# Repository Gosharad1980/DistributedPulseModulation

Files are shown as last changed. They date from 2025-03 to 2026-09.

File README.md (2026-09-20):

# DistributedPulseModulation

Distributed pulse modulation done like with the old P82C150, but with descrete components

## Theory of operation

With a regular Pulse Width Modulation (PWM), all the pulses are grouped in a same and unique pulse over the whole period.
On Distributed Pulse Modulation (DPM) and Dyadic Descrete Pulse Modulation (DDPM), the aim is to distribute all the "sub-pulses" throughout the whole period.

## Two advantages :
* spectrum with more high frequencies than PWM : easier filtering in case of A/D conversion
* as the pulse distribution is continuously evaluated : a threshold modification, before the period end, is taken into account without delay

### Old P82C150 for DPM implementation
[P82C150 - Application note](https://www.nxp.com/docs/en/application-note/AN94088.pdf)

[P82C150 datasheet](https://www.digchip.com/datasheets/parts/datasheet/364/P82C150AHT-pdf.php)

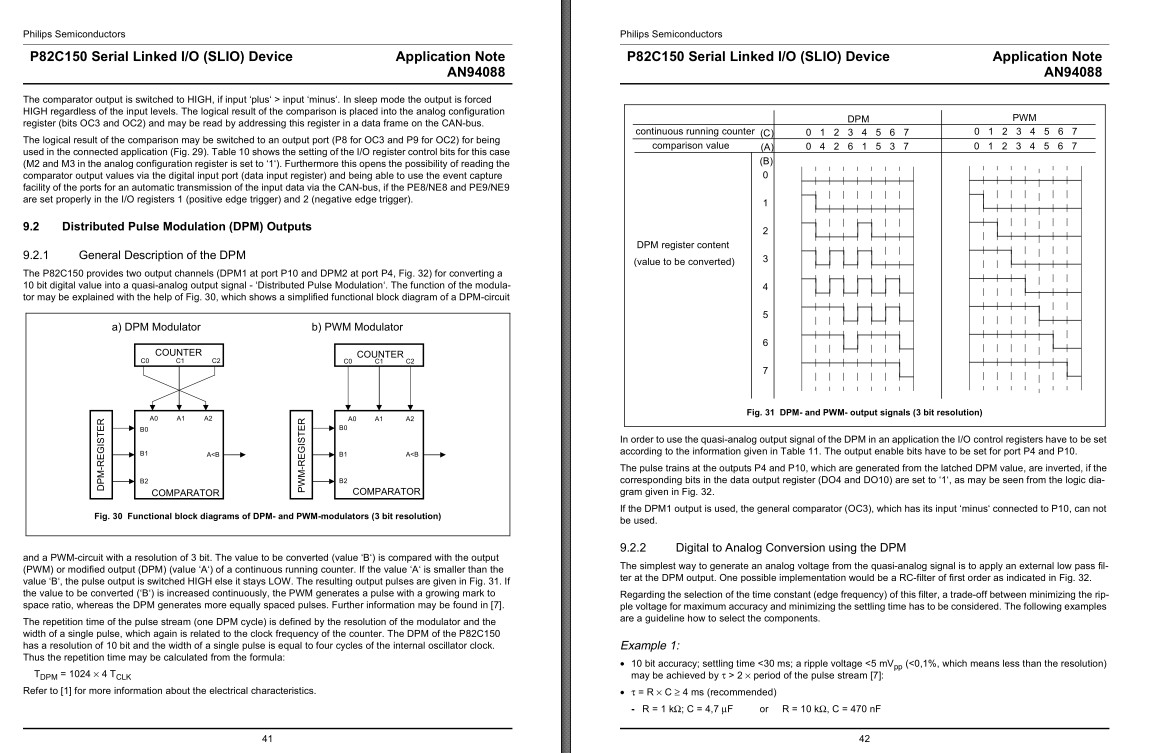
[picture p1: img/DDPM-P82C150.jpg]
DDPM-P82C150


### DDPM implementation based on Paolo S. Crovetti thesis
[Thèse : Paolo S. Crovetti](https://www.researchgate.net/publication/309012492_All-Digital_High_Resolution_DA_Conversion_by_Dyadic_Digital_Pulse_Modulation)

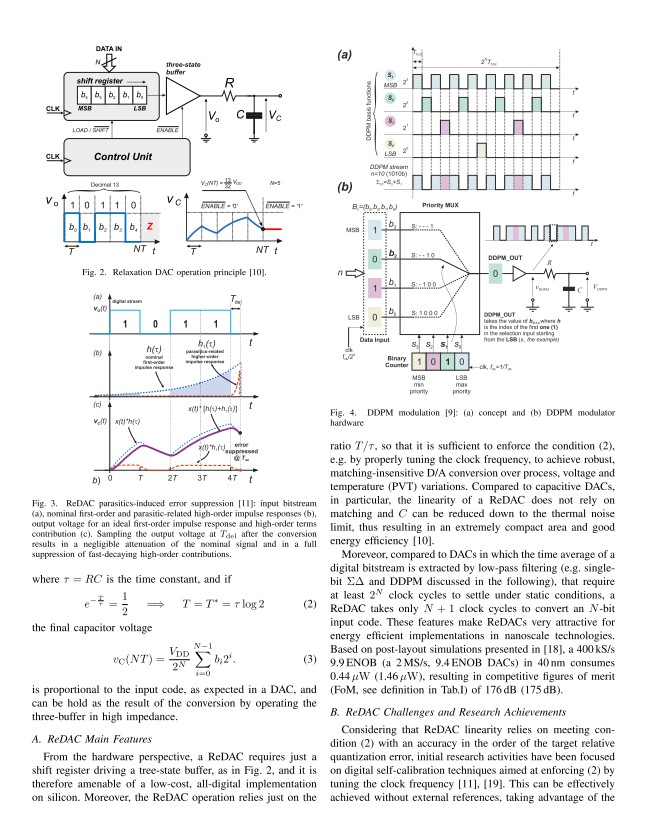
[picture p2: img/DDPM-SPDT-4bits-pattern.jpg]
DDPM-SPDT-4bits-pattern


## The breakout board

###  Features
	PWM (Pulse Width Modulation)
	DPM P82C150-like (Distributed Pulse Modulation)
	DDPM (Dyadic Discrete Pulse Modulation)

### MCP23017 Port A & B

	MCP23017 is an I2C 16bits IO expander
	Port A & B are used to control the board
	Prescaler decoding values :
	0x00	1
	0x01	2
	0x02	8
	0x03	16
	0x04	64
	0x05	256
	0x06	1024
	0x07	4096

Port A & B

### Overview

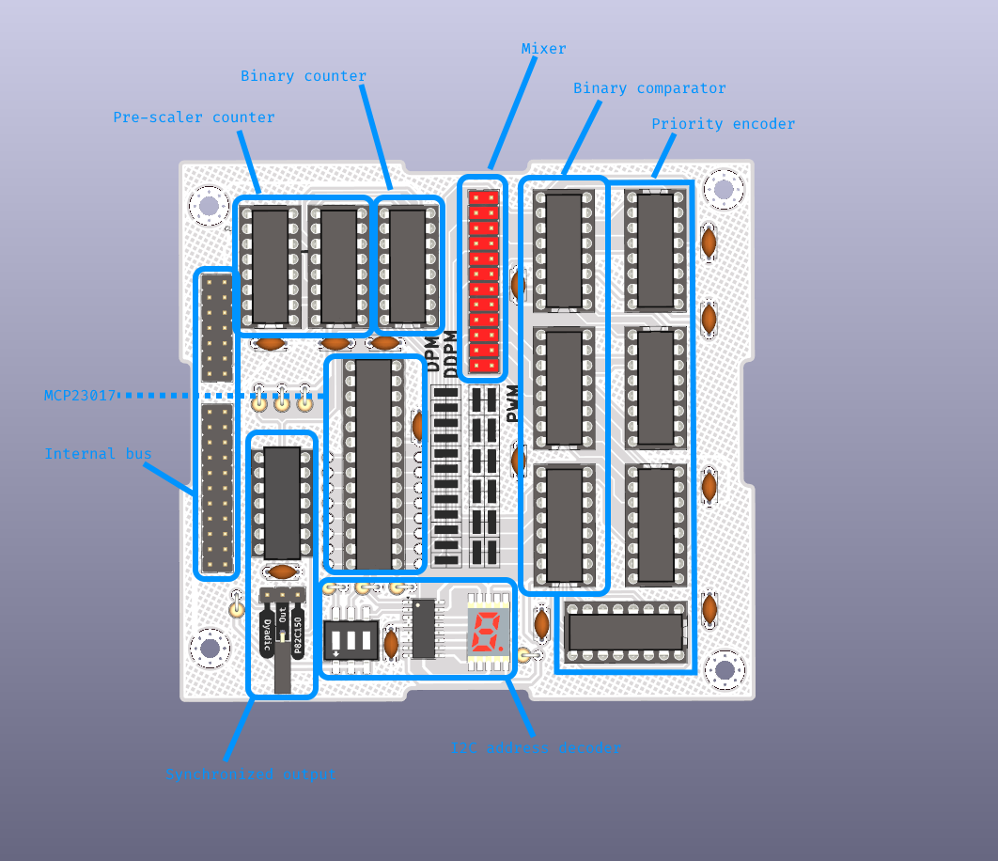
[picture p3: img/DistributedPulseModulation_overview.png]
DistributedPulseModulation_overview


## Choose your feature and do not populate the useless chips

### PWM

* do not populate the CD74HCT4053
* place the jumpers as describe in the silkscreen schematic (PWM)

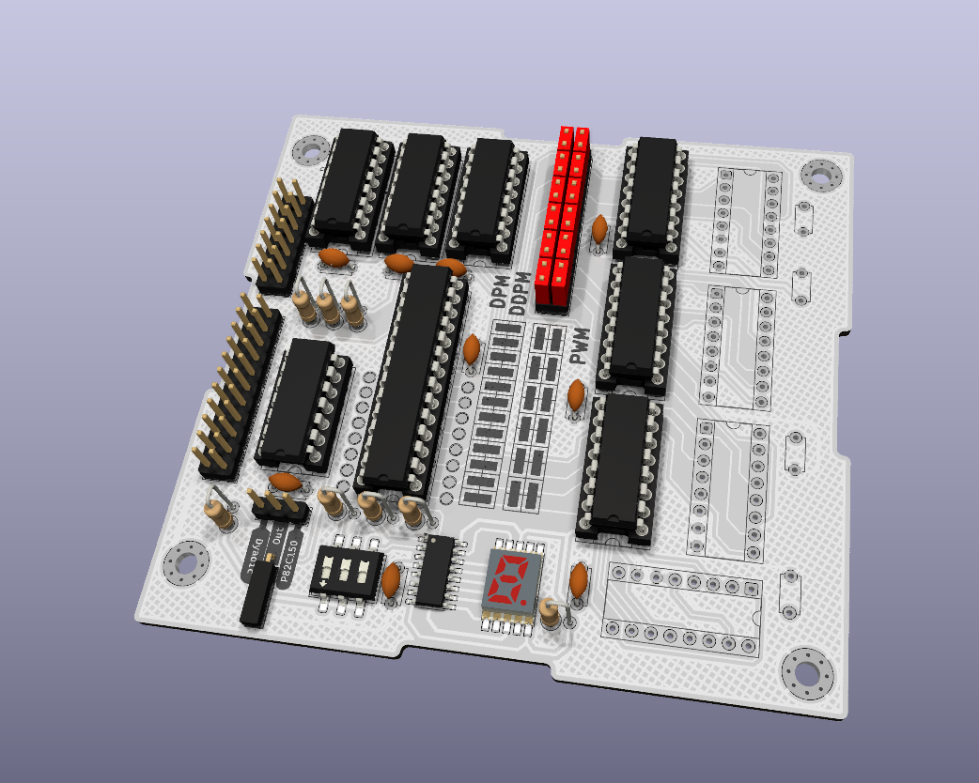
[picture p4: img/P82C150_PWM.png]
P82C150_PWM


### DPM

* do not populate the CD74HCT4053
* place the jumpers as describe in the silkscreen schematic (DPM/DDPM)

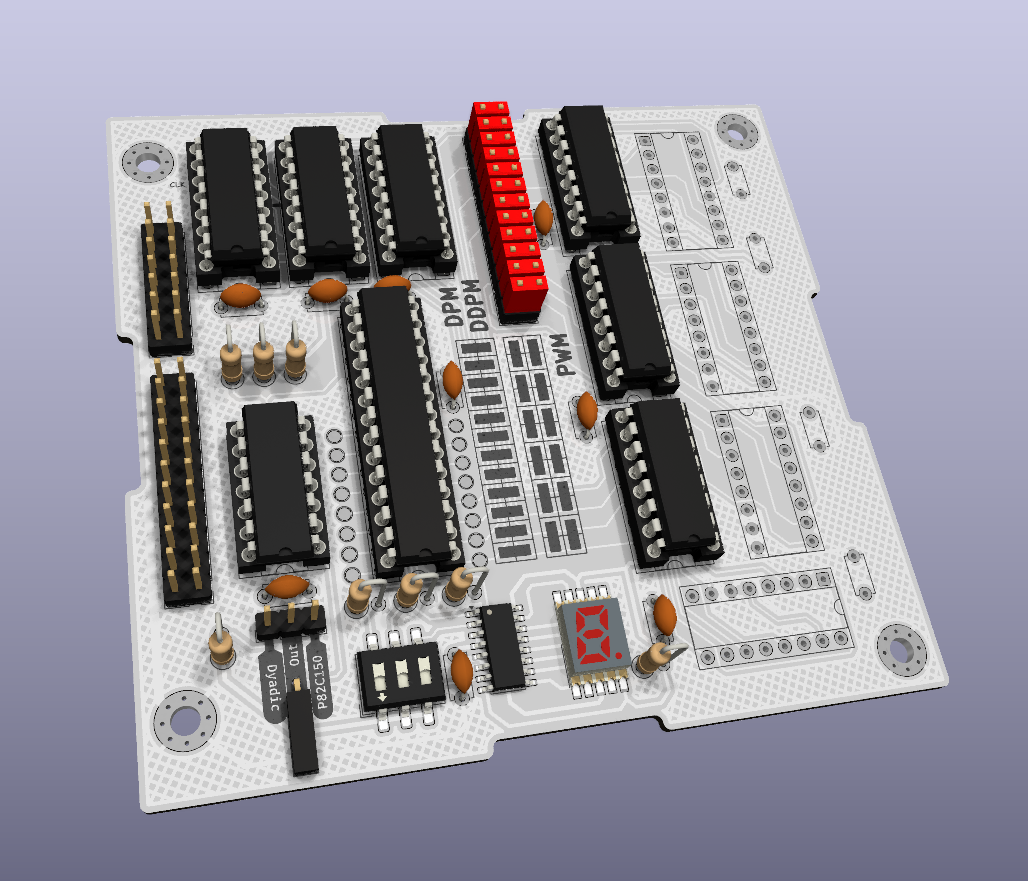
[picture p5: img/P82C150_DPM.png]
P82C150_DPM


### DDPM

* do not populate the 74LS85
* place the jumpers as describe in the silkscreen schematic (DPM/DDPM)

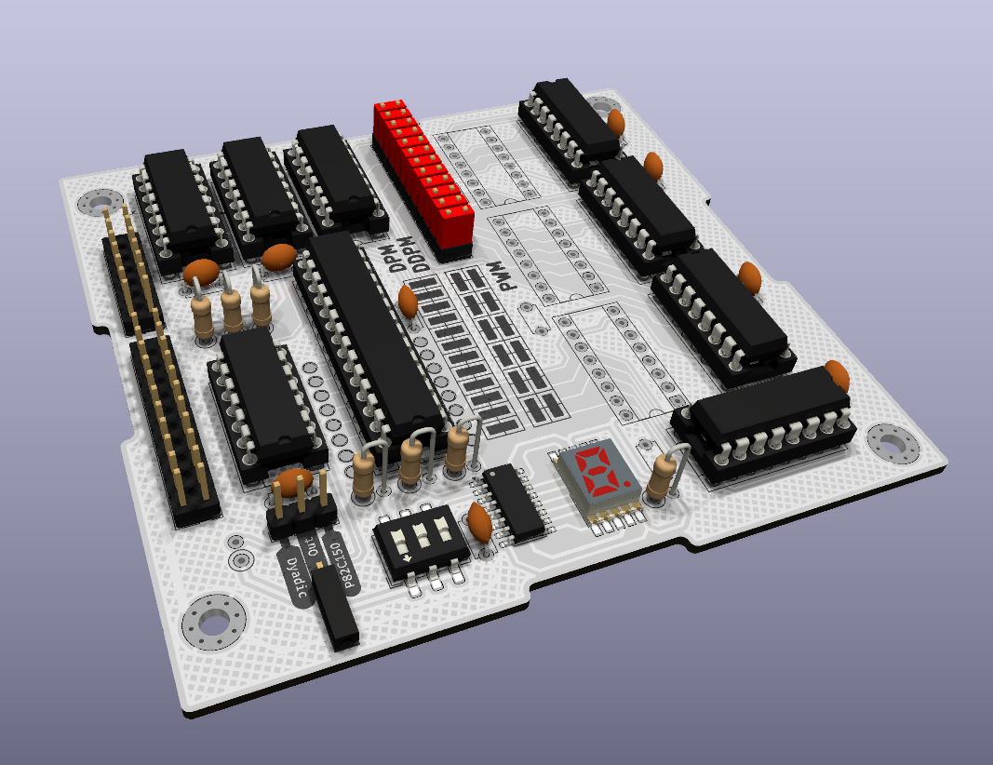
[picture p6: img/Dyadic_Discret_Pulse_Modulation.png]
Dyadic_Discret_Pulse_Modulation


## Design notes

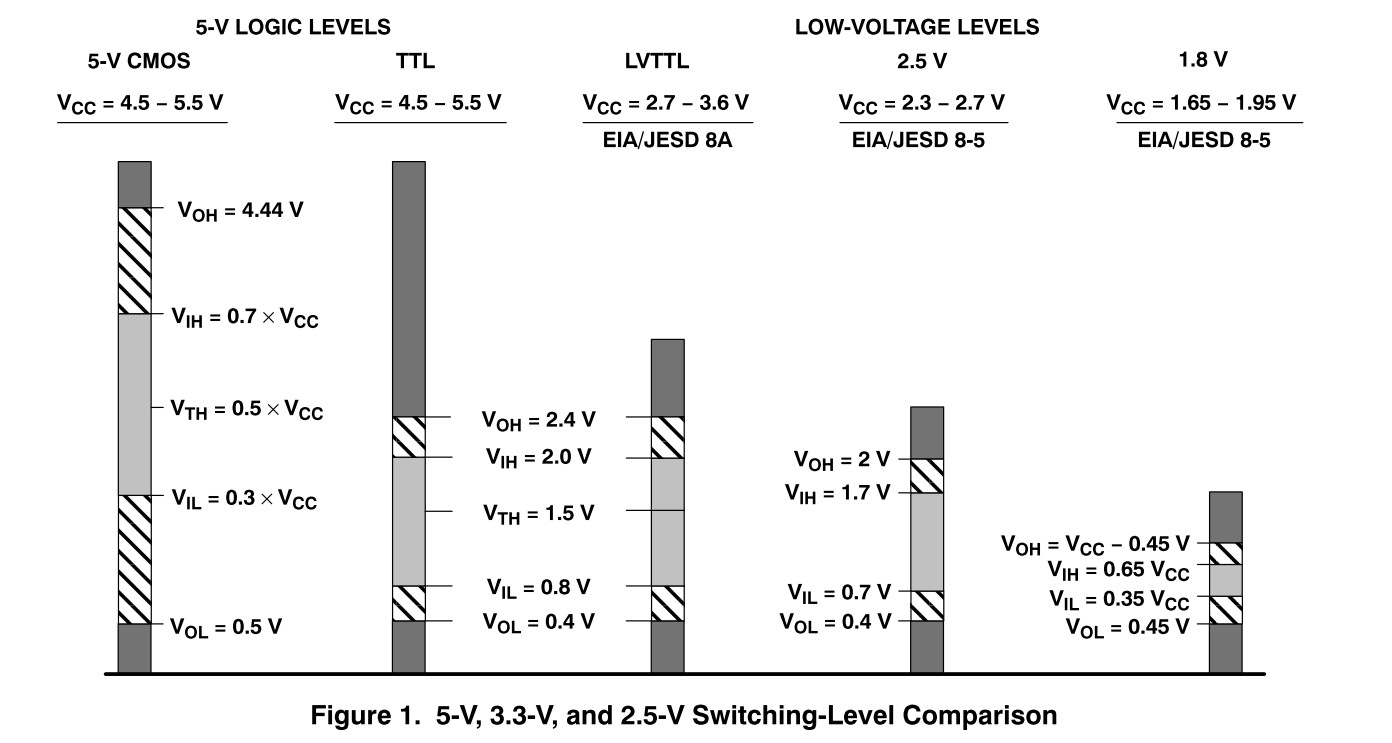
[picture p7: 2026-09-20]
img/Comparaison_tension_CMOS_vs_TTL.jpg

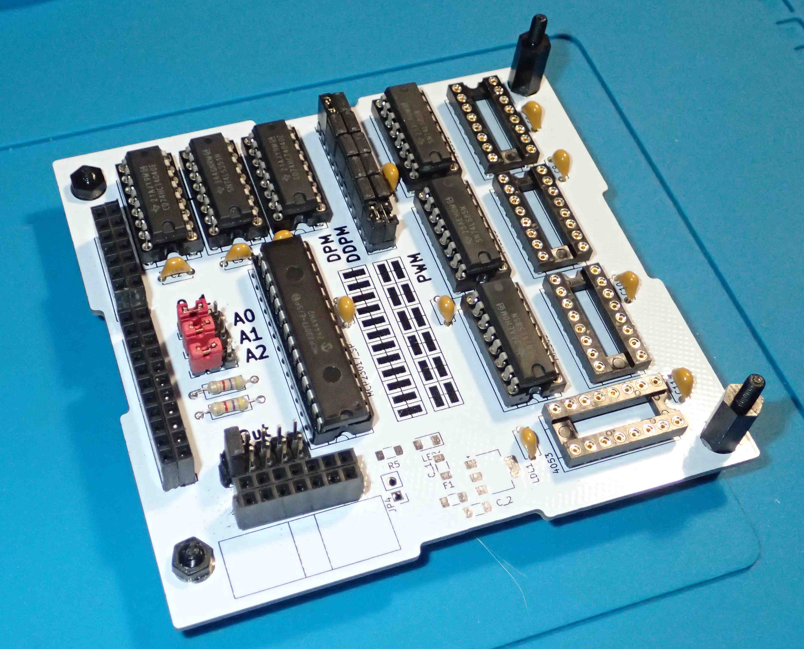
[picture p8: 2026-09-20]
img/photo_board.jpg

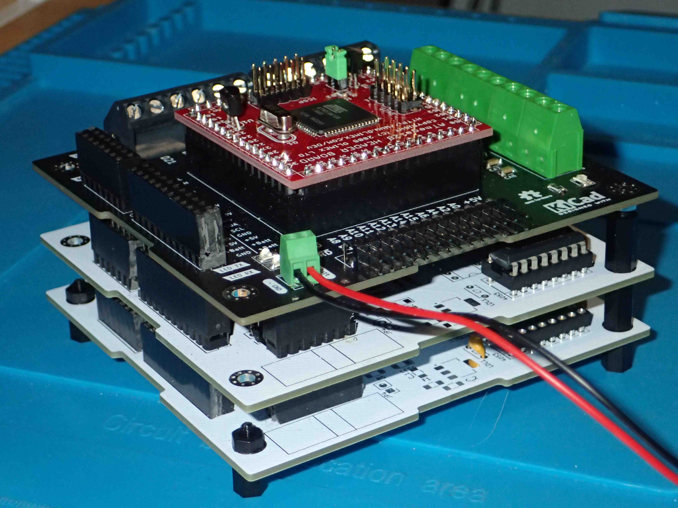
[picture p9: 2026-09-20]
img/photo_stack.jpg

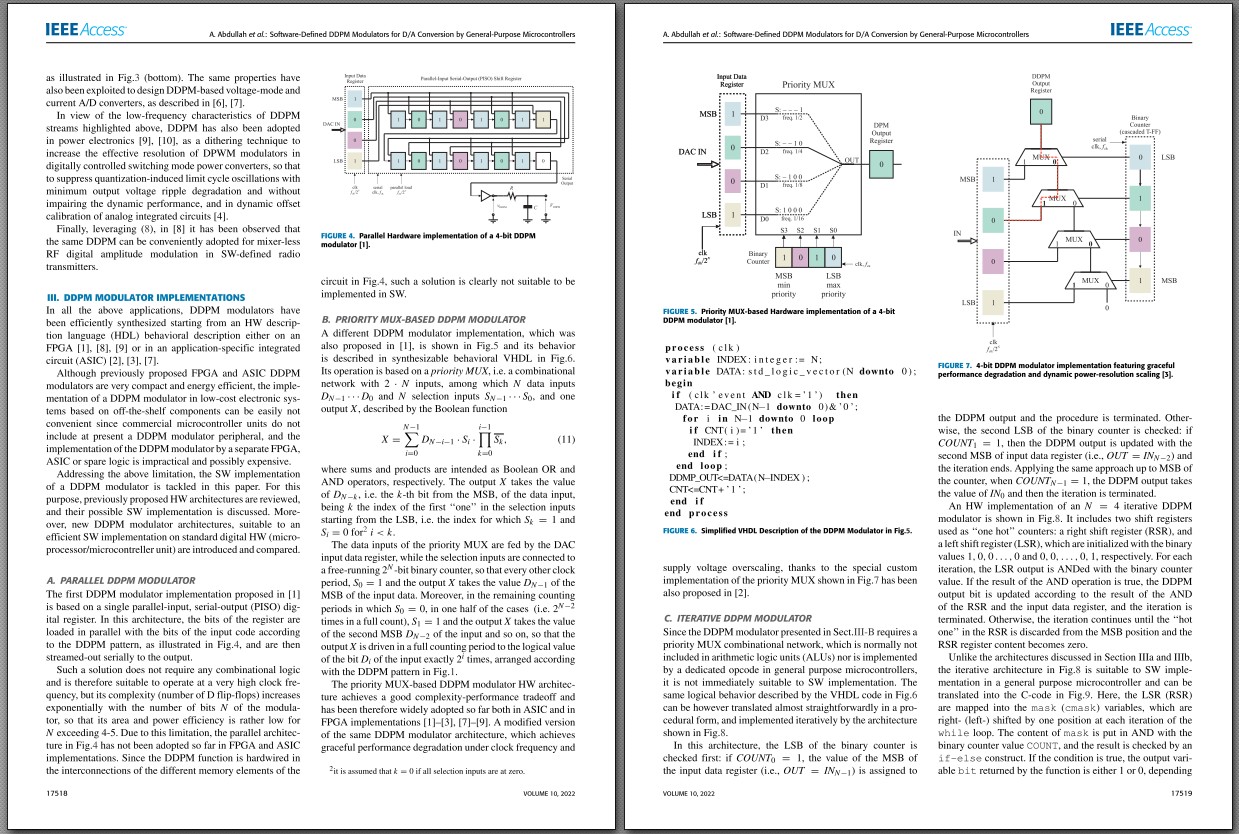
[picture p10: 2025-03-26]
img/DDPM-SPDT-4bits.jpg

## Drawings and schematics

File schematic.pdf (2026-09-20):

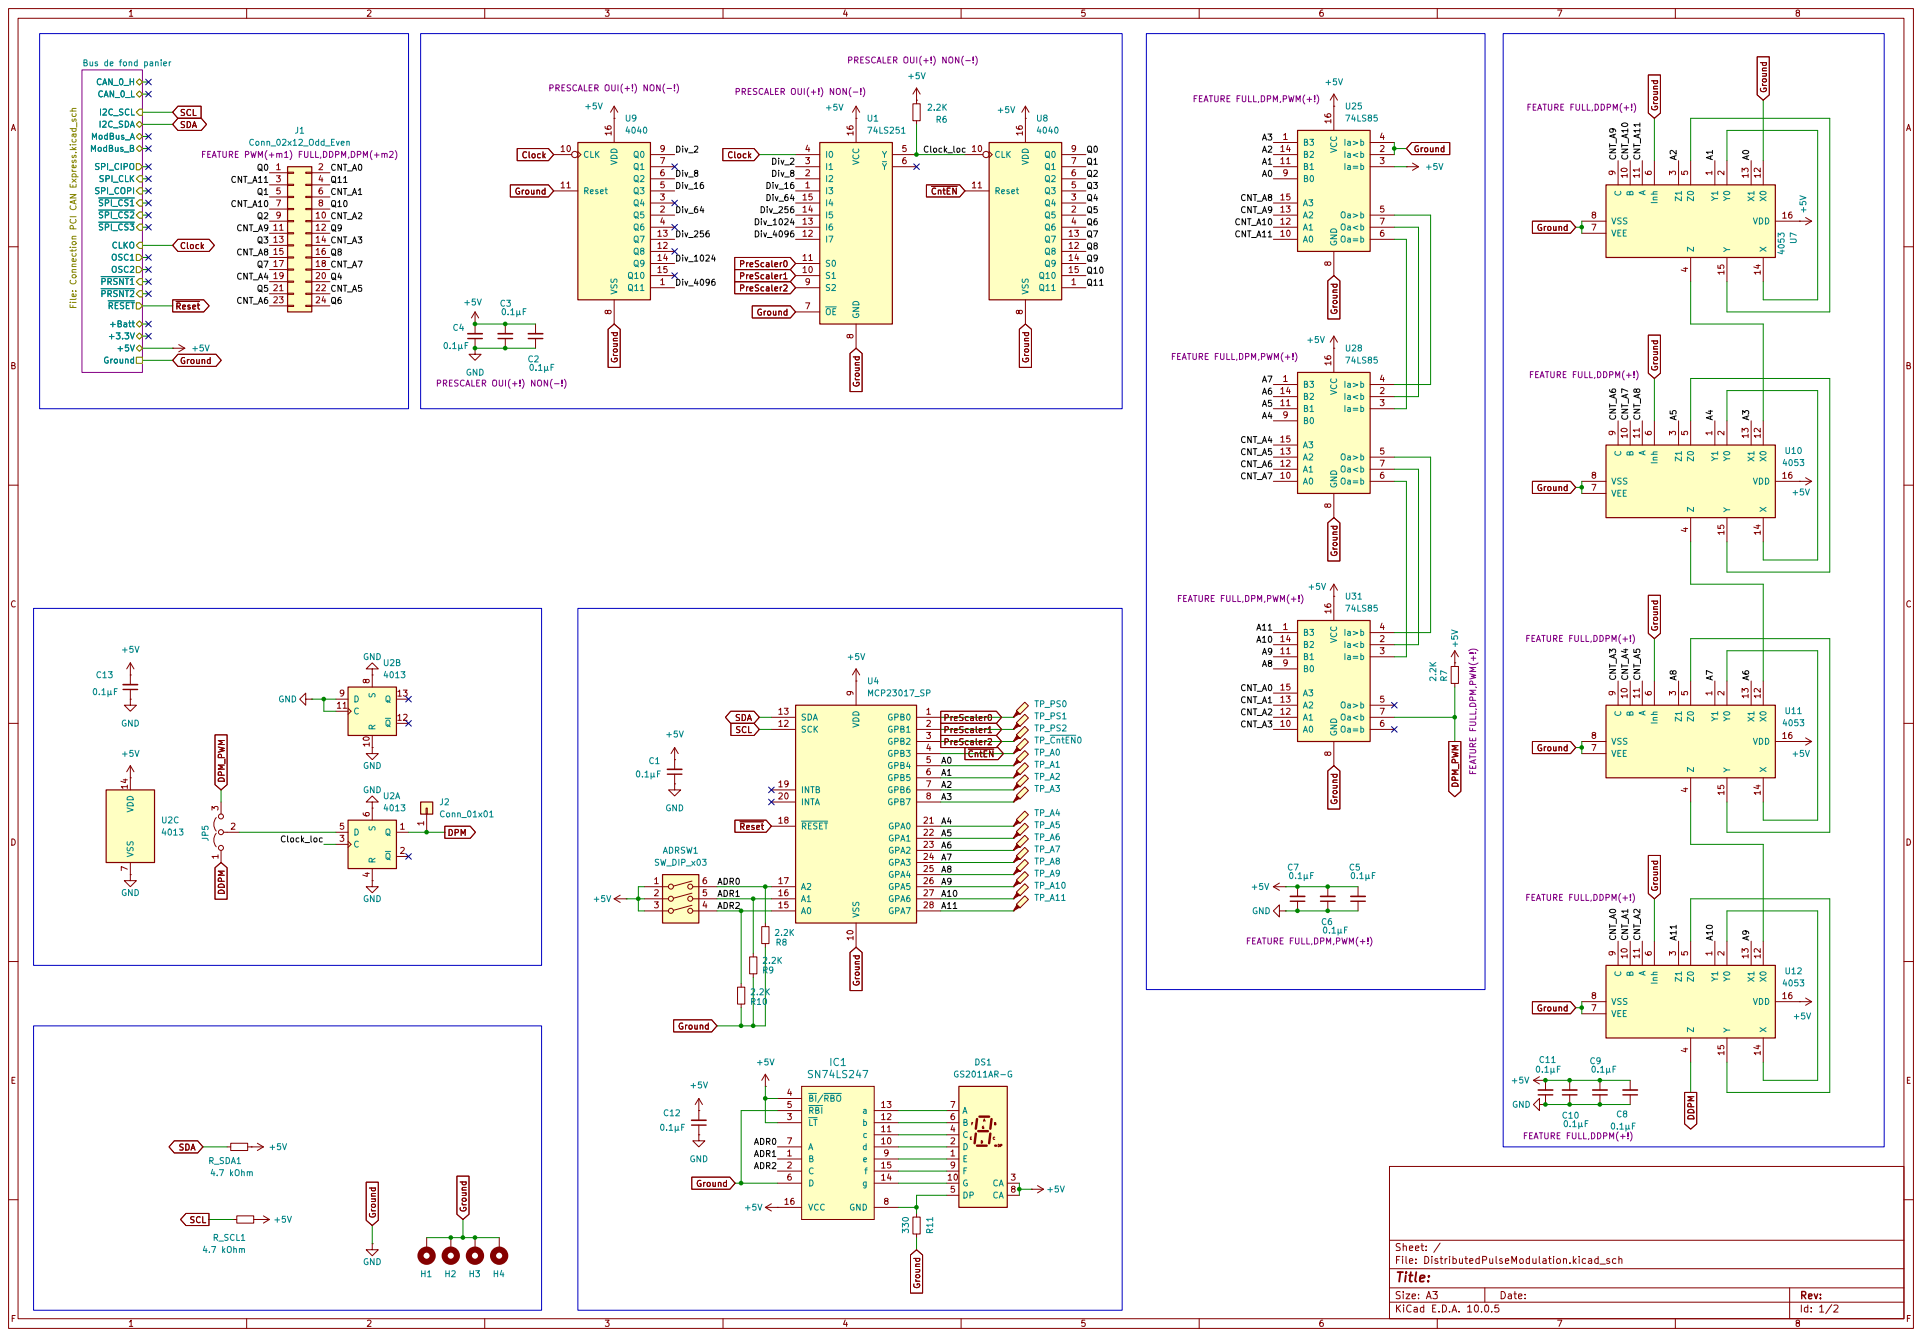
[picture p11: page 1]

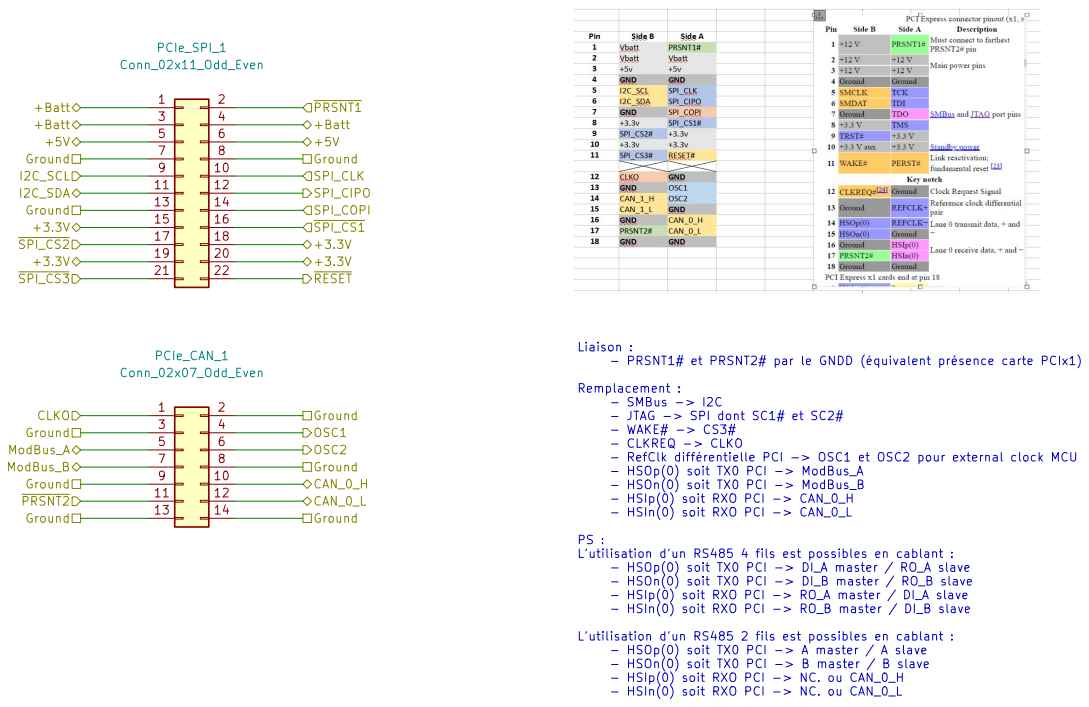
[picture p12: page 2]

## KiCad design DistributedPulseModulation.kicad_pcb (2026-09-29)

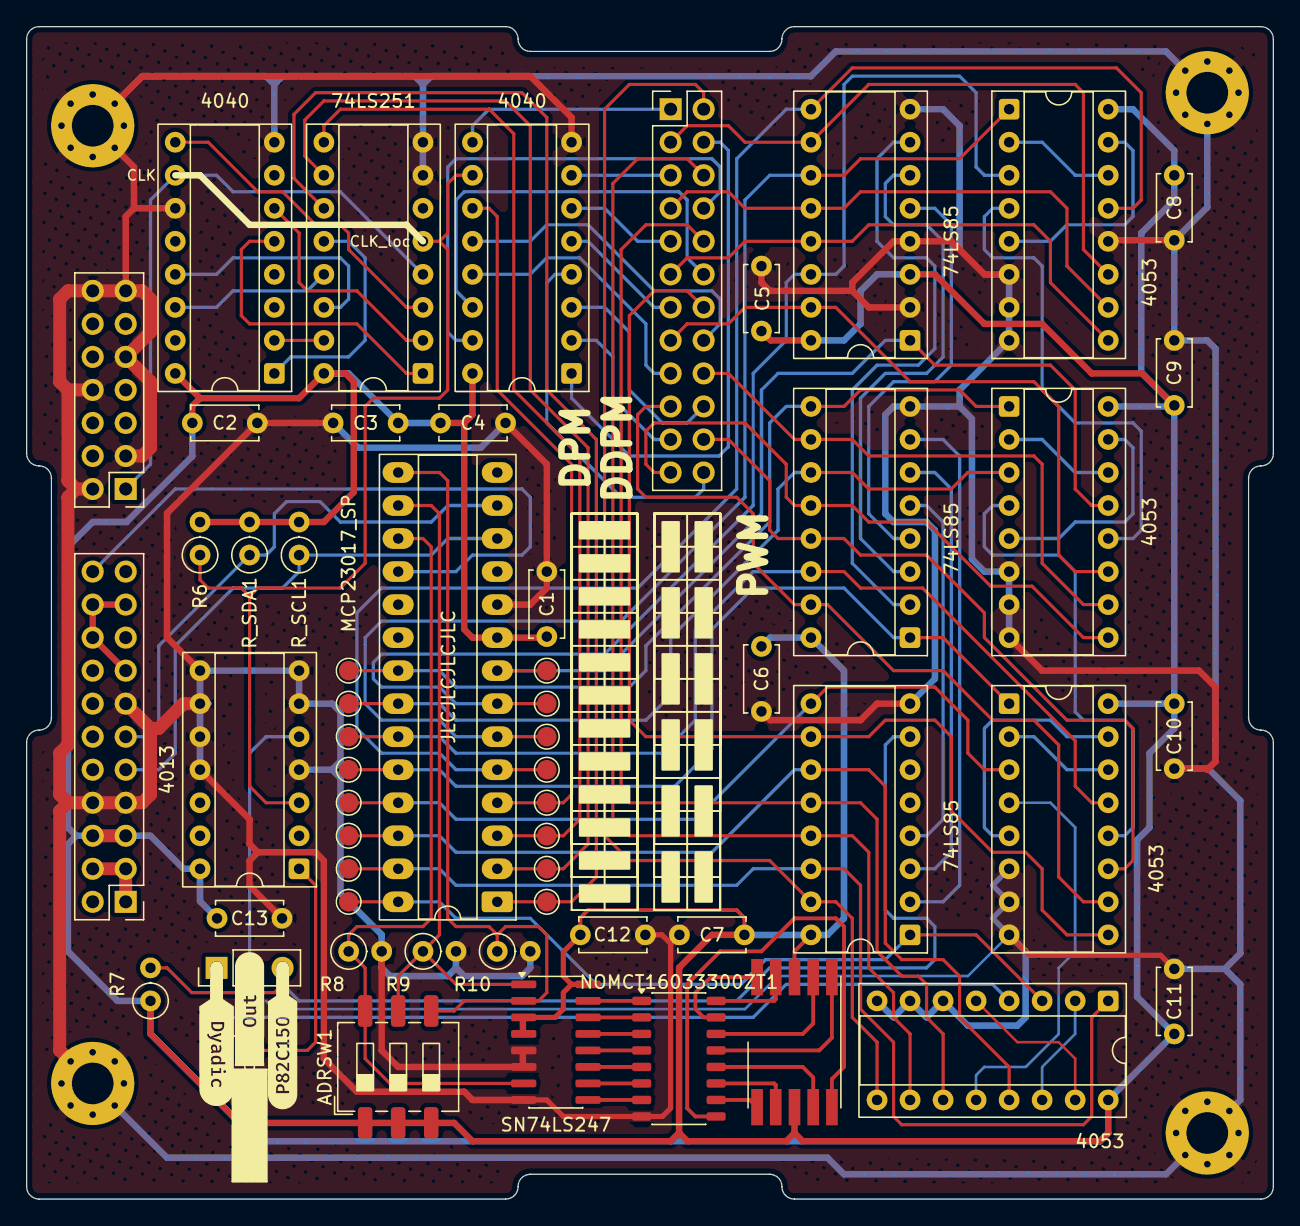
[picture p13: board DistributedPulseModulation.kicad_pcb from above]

Board: 2 copper layers, 95.9 x 90.2 mm, 65 parts (1 on the bottom side), 95 nets.

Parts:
ADRSW1: SW_DIP_x03; SW_DIP_SPSTx03_Slide_6.7x9.18mm_W8.61mm_P2.54mm_LowProfile
C1, C2, C3, C4, C5, C6, C7, C8, C9, C10, C11, C12, C13: 0.1µF; C_Disc_D5.0mm_W2.5mm_P5.00mm
DS1: GS2011AR-G; KCSC02-105
H1, H2, H3, H4: MountingHole_Pad; MountingHole_3.2mm_M3_Pad_Via
IC1: SN74LS247; SOIC-16_3.9x9.9mm_P1.27mm
J1: Conn_02x12_Odd_Even; PinHeader_2x12_P2.54mm_Vertical
J2: Conn_01x01; PinSocket_1x01_P2.54mm_Horizontal
JP5: Jumper_3_Open; PinHeader_1x03_P2.54mm_Vertical
NOMCT16033300ZT1: Conn_02x08_Counter_Clockwise; JEITA_SOIC-16_3.9x9.9mm_P1.27mm
PCIe_CAN_1: Conn_02x07_Odd_Even; PinHeader_2x07_P2.54mm_Vertical
PCIe_SPI_1: Conn_02x11_Odd_Even; PinHeader_2x11_P2.54mm_Vertical
R6, R7, R8, R9, R10: 2.2K; R_Axial_DIN0207_L6.3mm_D2.5mm_P2.54mm_Vertical
R_SCL1: 4.7 kOhm; R_Axial_DIN0207_L6.3mm_D2.5mm_P2.54mm_Vertical
R_SDA1: 4.7 kOhm; R_Axial_DIN0207_L6.3mm_D2.5mm_P2.54mm_Vertical
TP_A0, TP_A1, TP_A2, TP_A3, TP_A4, TP_A5, TP_A6, TP_A7, TP_A8, TP_A9, TP_A10, TP_A11: TestPoint_Probe; TestPoint_Pad_D1.5mm
TP_PS0, TP_PS1, TP_PS2: TestPoint_Probe; TestPoint_Pad_D1.5mm
TP_~{CntEN}0: TestPoint_Probe; TestPoint_Pad_D1.5mm
U1: 74LS251; DIP-16_W7.62mm_Socket
U2: 4013; DIP-14_W7.62mm_Socket
U4: MCP23017_SP; DIP-28_W7.62mm_Socket_LongPads
U7, U10, U11, U12: 4053; DIP-16_W7.62mm_Socket
U8, U9: 4040; DIP-16_W7.62mm_Socket
U25, U28, U31: 74LS85; DIP-16_W7.62mm_Socket
kibuzzard-6AAFCDBF: G***; kibuzzard-6AAFCDBF
kibuzzard-68110D32: G***; kibuzzard-68110D32
kibuzzard-6811091F: G***; kibuzzard-6811091F
kibuzzard-68110930: G***; kibuzzard-68110930

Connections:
+5V: ADRSW1.1, ADRSW1.2, ADRSW1.3, C1.2, C2.2, C3.2, C4.2, C5.2, C6.2, C7.2, C8.2, C9.2, C10.2, C11.2, C12.2, C13.2, DS1.3 (CA), DS1.8 (CA), IC1.3 (~LT), IC1.4 (~BI/~RBO), IC1.16 (VCC), PCIe_SPI_1.5, PCIe_SPI_1.6, R6.2, R7.1, R_SCL1.2, R_SDA1.2, U1.16 (VCC), U2.14 (VDD), U4.9 (VDD), U7.16 (VDD), U8.16 (VDD), U9.16 (VDD), U10.16 (VDD), U11.16 (VDD), U12.16 (VDD), U25.3 (Ia=b), U25.16 (VCC), U28.16 (VCC), U31.16 (VCC)
/A0: TP_A0.1 (1_1), U4.5 (GPB4), U7.13 (X1), U25.9 (B0)
/A1: TP_A1.1 (1_1), U4.6 (GPB5), U7.1 (Y1), U25.11 (B1)
/A2: TP_A2.1 (1_1), U4.7 (GPB6), U7.3 (Z1), U25.14 (B2)
/A3: TP_A3.1 (1_1), U4.8 (GPB7), U10.13 (X1), U25.1 (B3)
/A4: TP_A4.1 (1_1), U4.21 (GPA0), U10.1 (Y1), U28.9 (B0)
/A5: TP_A5.1 (1_1), U4.22 (GPA1), U10.3 (Z1), U28.11 (B1)
/A6: TP_A6.1 (1_1), U4.23 (GPA2), U11.13 (X1), U28.14 (B2)
/A7: TP_A7.1 (1_1), U4.24 (GPA3), U11.1 (Y1), U28.1 (B3)
/A8: TP_A8.1 (1_1), U4.25 (GPA4), U11.3 (Z1), U31.9 (B0)
/A9: TP_A9.1 (1_1), U4.26 (GPA5), U12.13 (X1), U31.11 (B1)
/A10: TP_A10.1 (1_1), U4.27 (GPA6), U12.1 (Y1), U31.14 (B2)
/A11: TP_A11.1 (1_1), U4.28 (GPA7), U12.3 (Z1), U31.1 (B3)
/ADR0: ADRSW1.6, IC1.7 (A), R8.1, U4.17 (A2)
/ADR1: ADRSW1.5, IC1.1 (B), R9.1, U4.16 (A1)
/ADR2: ADRSW1.4, IC1.2 (C), R10.1, U4.15 (A0)
/Bus de fond panier/+3.3V: PCIe_SPI_1.15, PCIe_SPI_1.18, PCIe_SPI_1.19, PCIe_SPI_1.20
/Bus de fond panier/+Batt: PCIe_SPI_1.1, PCIe_SPI_1.3, PCIe_SPI_1.4
/CNT_A0: J1.2, U12.9 (C), U31.15 (A3)
/CNT_A1: J1.6, U12.10 (B), U31.13 (A2)
/CNT_A2: J1.10, U12.11 (A), U31.12 (A1)
/CNT_A3: J1.14, U11.9 (C), U31.10 (A0)
/CNT_A4: J1.19, U11.10 (B), U28.15 (A3)
/CNT_A5: J1.22, U11.11 (A), U28.13 (A2)
/CNT_A6: J1.23, U10.9 (C), U28.12 (A1)
/CNT_A7: J1.18, U10.10 (B), U28.10 (A0)
/CNT_A8: J1.15, U10.11 (A), U25.15 (A3)
/CNT_A9: J1.11, U7.9 (C), U25.13 (A2)
/CNT_A10: J1.7, U7.10 (B), U25.12 (A1)
/CNT_A11: J1.3, U7.11 (A), U25.10 (A0)
/Clock_loc: R6.1, U1.5 (Y), U2.3 (C), U8.10 (CLK)
/Div_2: U1.3 (I1), U9.9 (Q0)
/Div_8: U1.2 (I2), U9.6 (Q2)
/Div_16: U1.1 (I3), U9.5 (Q3)
/Div_64: U1.15 (I4), U9.2 (Q5)
/Div_256: U1.14 (I5), U9.13 (Q7)
/Div_1024: U1.13 (I6), U9.14 (Q9)
/Div_4096: U1.12 (I7), U9.1 (Q11)
/Q0: J1.1, U8.9 (Q0)
/Q1: J1.5, U8.7 (Q1)
/Q2: J1.9, U8.6 (Q2)
/Q3: J1.13, U8.5 (Q3)
/Q4: J1.20, U8.3 (Q4)
/Q5: J1.21, U8.2 (Q5)
/Q6: J1.24, U8.4 (Q6)
/Q7: J1.17, U8.13 (Q7)
/Q8: J1.16, U8.12 (Q8)
/Q9: J1.12, U8.14 (Q9)
/Q10: J1.8, U8.15 (Q10)
/Q11: J1.4, U8.1 (Q11)
Clock: PCIe_CAN_1.1, U1.4 (I0), U9.10 (CLK)
DDPM: JP5.1 (A), U12.4 (Z)
DPM: J2.1 (Pin_1_1), U2.1 (Q)
DPM_PWM: JP5.3 (B), R7.2, U31.7 (Oa<b)
Ground: C1.1, C2.1, C3.1, C4.1, C5.1, C6.1, C7.1, C8.1, C9.1, C10.1, C11.1, C12.1, C13.1, H1.1 (1_1), H2.1 (1_1), H3.1 (1_1), H4.1 (1_1), IC1.5 (~RBI), IC1.6 (D), IC1.8 (GND), NOMCT16033300ZT1.8, PCIe_CAN_1.2, PCIe_CAN_1.3, PCIe_CAN_1.8, PCIe_CAN_1.9, PCIe_CAN_1.13, PCIe_CAN_1.14, PCIe_SPI_1.7, PCIe_SPI_1.8, PCIe_SPI_1.13, R8.2, R9.2, R10.2, U1.7 (~OE), U1.8 (GND), U2.4 (R), U2.6 (S), U2.7 (VSS), U2.8 (S), U2.9 (D), U2.10 (R), U2.11 (C), U4.10 (VSS), U7.6 (Inh), U7.7 (VEE), U7.8 (VSS), U7.12 (X0), U8.8 (VSS), U9.8 (VSS), U9.11 (Reset), U10.6 (Inh), U10.7 (VEE), U10.8 (VSS), U11.6 (Inh), U11.7 (VEE), U11.8 (VSS), U12.6 (Inh), U12.7 (VEE), U12.8 (VSS), U25.2 (Ia<b), U25.4 (Ia>b), U25.8 (GND), U28.8 (GND), U31.8 (GND)
unnamed: DS1.7 (A), NOMCT16033300ZT1.14
unnamed: DS1.6 (B), NOMCT16033300ZT1.13
unnamed: DS1.4 (C), NOMCT16033300ZT1.12
unnamed: DS1.2 (D), NOMCT16033300ZT1.11
unnamed: DS1.5 (DP), NOMCT16033300ZT1.9
unnamed: DS1.1 (E), NOMCT16033300ZT1.10
unnamed: DS1.9 (F), NOMCT16033300ZT1.16
unnamed: DS1.10 (G), NOMCT16033300ZT1.15
unnamed: IC1.13 (a), NOMCT16033300ZT1.3
unnamed: IC1.12 (b), NOMCT16033300ZT1.4
unnamed: IC1.11 (c), NOMCT16033300ZT1.5
unnamed: IC1.10 (d), NOMCT16033300ZT1.6
unnamed: IC1.9 (e), NOMCT16033300ZT1.7
unnamed: IC1.15 (f), NOMCT16033300ZT1.1
unnamed: IC1.14 (g), NOMCT16033300ZT1.2
unnamed: JP5.2 (C), U2.5 (D)
unnamed: U7.2 (Y0), U7.14 (X)
unnamed: U7.5 (Z0), U7.15 (Y)
unnamed: U7.4 (Z), U10.12 (X0)
unnamed: U10.2 (Y0), U10.14 (X)
unnamed: U10.5 (Z0), U10.15 (Y)
unnamed: U10.4 (Z), U11.12 (X0)
unnamed: U11.2 (Y0), U11.14 (X)
unnamed: U11.5 (Z0), U11.15 (Y)
unnamed: U11.4 (Z), U12.12 (X0)
unnamed: U12.2 (Y0), U12.14 (X)
unnamed: U12.5 (Z0), U12.15 (Y)
unnamed: U25.7 (Oa<b), U28.2 (Ia<b)
unnamed: U25.6 (Oa=b), U28.3 (Ia=b)
unnamed: U25.5 (Oa>b), U28.4 (Ia>b)
unnamed: U28.7 (Oa<b), U31.2 (Ia<b)
unnamed: U28.6 (Oa=b), U31.3 (Ia=b)
unnamed: U28.5 (Oa>b), U31.4 (Ia>b)
PreScaler0: TP_PS0.1 (1_1), U1.11 (S0), U4.1 (GPB0)
PreScaler1: TP_PS1.1 (1_1), U1.10 (S1), U4.2 (GPB1)
PreScaler2: TP_PS2.1 (1_1), U1.9 (S2), U4.3 (GPB2)
SCL: PCIe_SPI_1.9, R_SCL1.1, U4.12 (SCK)
SDA: PCIe_SPI_1.11, R_SDA1.1, U4.13 (SDA)
~CntEN: TP_~{CntEN}0.1 (1_1), U4.4 (GPB3), U8.11 (Reset)
~Reset: PCIe_SPI_1.22, U4.18 (~RESET)

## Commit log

2024-08-17 On démarre un nouveau projet mort-né
    [Connection PCI CAN Express.kicad_sch]
2024-08-20 DPM et DDPM implémentés Mouais bof pour ajouter ma DPM en code Gray
    Sinon OK Tiers pour en faire la branche 1
    [Connection PCI CAN Express.kicad_sch, DPM.kicad_pcb, DPM.kicad_sch]
2025-03-26 - Ajout de screenshots de doc
    [Connection PCI CAN Express.kicad_sch, DPM.kicad_pcb, DPM.kicad_sch]
2025-03-28 + 3 fonctionnalités : PWM, DPM & DDPM + début du routage de la carte
    [Connection PCI CAN Express.kicad_sch, DPM.kicad_pcb, DPM.kicad_sch]
2025-03-28 POPOPO !!!!! 1ere version du routage de la carte
    [DPM.kicad_pcb, DPM.kicad_sch]
2025-03-29 Ajout du prescaler TODO : - condensateurs de découplage - bouchon I2C
    [DPM.kicad_pcb, DPM.kicad_sch]
2025-03-29 Début de ré&vision pour ajouter des câblages
    [DPM.kicad_pcb, DPM.kicad_sch]
2025-03-29 Ajout pistes An sur DDPM Suppression du via des enfers Ajout jumpers pour DPM sur connecteur IDC-14 Début du silksreen
    TODO :
    - condensateurs de découplage
    - bouchon I2C
    [DPM.kicad_pcb, DPM.kicad_sch]
2025-03-29 Nouvelle liste de prescaler : 1 2 8 16 64 256 1024 4096
    [DPM.kicad_pcb, DPM.kicad_sch]
2025-03-30 - Condo UC - résintances pull-up I2C - D-latch 2G74 - routage - silkscreen
    [DPM.kicad_pcb, DPM.kicad_sch]
2025-03-30 Correction clock du 2G74 Reroutage léger
    [DPM.kicad_pcb, DPM.kicad_sch]
2025-03-30 Modification : PinOut des ports GPIOA et GPIOB
    [DPM.kicad_pcb, DPM.kicad_sch]
2025-03-31 Création modélisations sous Digital Correction routage des R SDA/SCL Ajout des screenshots de la carte
    [DPM.kicad_pcb, DPM.kicad_sch]
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2025-04-01 RETROFIT : connecteur perso PCIe_CAN pour compatibilité avec le CANduino128 comme microcontôleur maitre
    [Connection PCI CAN Express.kicad_sch, DistributedPulseModulation.kicad_pcb, DistributedPulseModulation.kicad_sch]
2025-04-02 AMELIORATION : simplification des routages de pistes
    [Connection PCI CAN Express.kicad_sch, DistributedPulseModulation.kicad_pcb, DistributedPulseModulation.kicad_sch]
2025-04-03 Fin de simplification du routage. Génération des Gerber.
    [Connection PCI CAN Express.kicad_sch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]
2025-04-04 Full rework : ADG333A 10x plus chers que cd74hct4053 Nouveau chips et nouveau routage JPP TT
    [Connection PCI CAN Express.kicad_sch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]
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2025-04-04 Enfin une version industrialisable et pas chers ? - correction du routage - replacement de condensateurs - génération des gerber
    [Connection PCI CAN Express.kicad_sch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]
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2025-04-05 Modification fonctionnelle : - PWM en "mode croisé" des jumpers - DPM en "mode direct" des jumpers comme le DDPM
    Routage
    [Connection PCI CAN Express.kicad_sch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]
2025-04-05 Utilisation de KiVar pour gérer les variantes du PCB :)
    [Connection PCI CAN Express.kicad_sch, DistributedPulseModulation.kicad_pcb, DistributedPulseModulation.kicad_sch]
2025-04-06 Feature : - DPM et DDPM sur même position de jumper - PWM sur jumpers en croisés
    KiVar :
    - création des 4 aspects FULL, PWM, DPM et DDPM
    Doc/img :
    - mise à jour du README.md
    - mise à jour des screeshots
    - intégration directe dans le projet des modèles 3D
    [Connection PCI CAN Express.kicad_sch, DistributedPulseModulation.kicad_pcb, DistributedPulseModulation.kicad_sch]
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2025-04-07 Ajout des fichiers JLCPCB à l'ignore list
    [DistributedPulseModulation.kicad_pcb]
2025-04-25 Correction position R_SDA, R_SCL, jumper A0, A1 et A2
    [DistributedPulseModulation-B_Cu.gbl, DistributedPulseModulation-B_Mask.gbs, DistributedPulseModulation-B_Paste.gbp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]
2025-04-27 Travaux préparatoire : V2.0 - Ajout jumper Dyadic vs P82C150 - B.Silkscreen major update
    - Suppression connecteur IDC
    - Ajout pinheader horizontal pour les 5 outputs
    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
    [Connection PCI CAN Express.kicad_sch, DistributedPulseModulation.kicad_pcb, DistributedPulseModulation.kicad_sch]
2025-04-27 Pré-version de la v2.0
    [Connection PCI CAN Express.kicad_sch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]
2025-04-29 Reroutage et passage de tous les composants côté Front
    [DistributedPulseModulation.kicad_pcb]
2025-04-29 V2.0 : SCH + PCB + Gerber
    [Connection PCI CAN Express.kicad_sch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]
2025-04-29 PCB_V2.0 delivery and README.md update
    [DistributedPulseModulation.kicad_pcb]
2025-05-08 Routage : légère modif de la route du GND
    [DistributedPulseModulation.kicad_pcb]
2025-05-08 RCA : 2.0->1.x - correction KiVar pour "mixer" - ajout /ClkEN au connecteur IDC14 - routage /ClkEN
    [Connection PCI CAN Express.kicad_sch, DistributedPulseModulation.kicad_pcb, DistributedPulseModulation.kicad_sch]
2025-05-08 Ajout test-points pour les ports A et B du MCP23017 Léger reroutage
    [Connection PCI CAN Express.kicad_sch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]
2025-05-10 Routage : Clock_loc on PIN6 of IDC-14
    [Connection PCI CAN Express.kicad_sch, DistributedPulseModulation.kicad_pcb, DistributedPulseModulation.kicad_sch]
2026-08-09 [UPGRADE] : KiCad10 + Voltage -> KICAD 10 -> CMOS vs TTL voltage compare
    [TODO]
    -> adding replacement circuit for Dlatch chip
    -> correction voltage bugs
    -> remove supply voltage regulator from PCB
    [Connection PCI CAN Express.kicad_sch, DistributedPulseModulation.kicad_sch]
2026-08-09 [UPGRADE] : ajout R6 pour pb tension entre TTL et CMOS - A jout de R6 (2.2K) en pull-uup sur la pin 5 du 74ls251 (TTL) en entrée du 74HCT4040 (CMOS)
    [DistributedPulseModulation.kicad_pcb, DistributedPulseModulation.kicad_sch]
2026-08-10 [UPGRADE] : ajout R7 pour pb tension entre TTL et CMOS - A jout de R7 (2.2K) en pull-up sur la sortie finale de la carte
    [DONE]
    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
    [DistributedPulseModulation.kicad_pcb, DistributedPulseModulation.kicad_sch]
2026-08-11 [UPGRADE] : V2.1 in progress :-)
    -> A jout de R7 (2.2K) en pull-up sur la sortie finale de la carte
    -> A jout de R7 (2.2K) en pull-up sur la sortie clock locale
    -> Bascule D sur sortie carte pour anti-rebond
    -> retrait régulateur de tension
    -> déplacement jumper d'adressage
    -> ajout décodeur BCD vers 7 segment
    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
    [DistributedPulseModulation.kicad_pcb, DistributedPulseModulation.kicad_sch]
2026-08-15 [update] : choix aficheurs et conv ; bug pin A1 ; condo ; doc pdf
    - choix du 7-segment en common anode
    - choix de decodeur DCBN vers 7-segments
    - bug routage pin A1 sur V2.0 de la carte
    - condo découplage sur D-latch
    - condo découplage sur DVBN->7-segments
    - ajout doc pdf work-in-progress
    [DistributedPulseModulation.kicad_pcb, DistributedPulseModulation.kicad_sch]
2026-08-15 [UPDATE] : KiVar ; doc pdf
    - adding KiVar command to some new parts
    - pdf datasheet list up-to-date
    [DistributedPulseModulation.kicad_pcb, DistributedPulseModulation.kicad_sch]
2026-08-29 UPDATE : doc + gerber - add schematic.pdf - generate gerber files
    [Connection PCI CAN Express.kicad_sch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]
2026-09-20 [UPDATE] : readme file and PCB silkscreen with PCB v2.2
    [DistributedPulseModulation.kicad_pcb]
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2026-09-29 [update] : missing resistors on the 7 segmznts display
    [DistributedPulseModulation-B_Cu.gbl, DistributedPulseModulation-B_Mask.gbs, DistributedPulseModulation-B_Paste.gbp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]
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
